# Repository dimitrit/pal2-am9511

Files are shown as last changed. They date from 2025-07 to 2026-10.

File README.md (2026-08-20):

AM9511 Module for the PAL-2
===========================

The AMD AM9511 Arithmetic Processing Unit, first produced in the late 
1970s, provides hardware support for high performance fixed and floating 
point arithmetic and a variety of floating point trigonometric and 
mathematical operations, for use with microprocessors of that period.

This repository provides schematics and board design for a module that
can be connected to the PAL-2 Expansion interface.

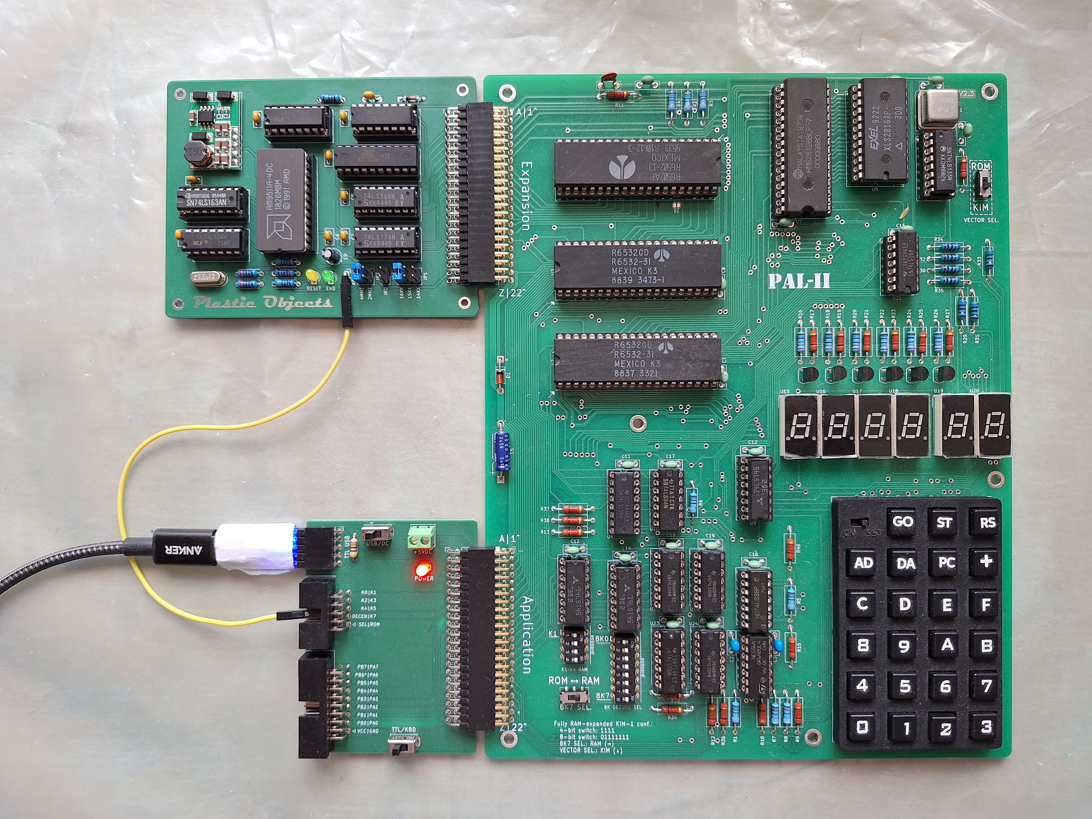
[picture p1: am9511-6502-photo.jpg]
module photo


The design is adapted from the work of Harris[1], who in turn based 
his implementation on designs by Kissel and Currie[2] in which they 
developed an experiment using a MOS 6502 microprocessor to control 
four AM9511A floating-point arithmetic units, and from Hart’s 
MICROCRUNCH[3] which also used the AM9511A (Intel 8231A) interfaced 
with a (Rockwell) 6502.

See [am9511-6502-description.pdf](am9511-6502-description.pdf) for a
full description of the interface circuit design and 
[am9511-6502-schematic.pdf](am9511-6502-schematic.pdf) for the schematic.

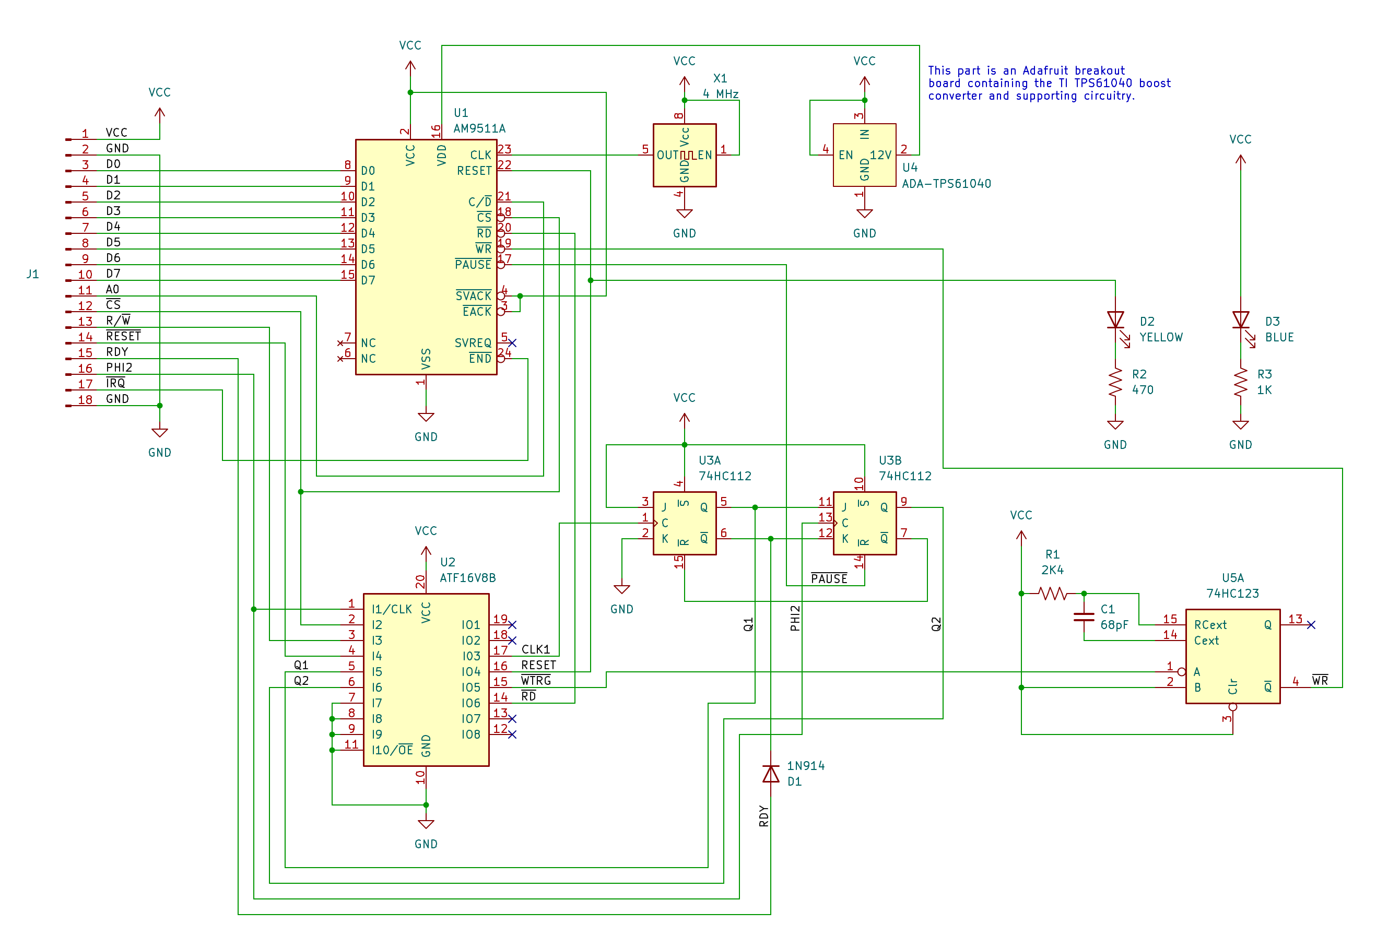
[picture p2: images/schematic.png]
Schematic


The specification here anticipates the use of an AM9511A clocked at
4 MHz. However, the same design will work with earlier versions of the 
AM9511, by setting JP to 2Mhz or by swapping the 4 MHz clock oscillator 
with a unit of an appropriately lower speed.

The `logic` folder contains the programming details for the ATF16V8B
used in the circuit, as produced by [Galette](https://github.com/simon-frankau/galette) 
from the `am9511-logic.pld` source file. The provided JEDEC file
(`am9511-logic.jed`) can be easily programmed into an ATF16V8B using 
[minipro](https://gitlab.com/DavidGriffith/minipro).

Also included in the `docs` folder are source documents cited below, as 
well as datasheets and supplementary documents for the AM9511.

---
1. Harris, CE: "AM9511 Interface Module for the 6502"; July 2025; [GitHub](https://github.com/ceharris/am9511-6502)
2. Kissel, R and Currie, J: "Hardware Math for the 6502 Microprocessor"; 
   July 1985; NASA TM-86517
3. Hart, J: "MICROCRUNCH: An Ultra-Fast Arithmetic Computing System 
   (part 1)"; August 1981; MICRO - the 6502/6809 Journal (No. 39)

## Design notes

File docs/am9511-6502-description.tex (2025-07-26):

\documentclass[11pt, letterpaper]{article}
\usepackage[letterpaper, margin=1in]{geometry}
\usepackage{graphicx}
\usepackage[dvipsnames]{xcolor}
\definecolor{linkbordergray}{rgb}{0.8,0.8,0.8}
\usepackage[linkbordercolor=linkbordergray]{hyperref}
\graphicspath{{images/}}

\newcommand{\overbar}[1]{\mkern 1.5mu\overline{\mkern-1.5mu#1\mkern-1.5mu}\mkern 1.5mu}

\title{AM9511 Interface for the 6502}
\author{Carl Harris}
\date{December 2024}
\begin{document}
\maketitle
\noindent 
The AMD AM9511 Arithmetic Processing Unit, first produced in the late 1970s, 
provides high performance fixed or floating point arithmetic as well as
common transcendental functions. It provides an excellent enhancement to any 
retro-computer that will be used to perform fixed-point or floating-point 
mathematical operations. At present, these parts are obtainable from various 
suppliers as new-old stock or used stock.

This article describes an interface allowing the AM9511A to be directly 
connected to the bus of the 6502 microprocessor. It is adapted from the work 
of Kissel and Currie\footnote{Kissel, R and Currie, J: 
\emph{Hardware Math for the 6502 Microprocessor}; July 1985; 
NASA TM-86517} in which they developed an experiment using a MOS 6502 
microprocessor to control four AM9511A floating-point arithmetic units. It
also includes elements of Hart’s MICROCRUNCH\footnote{Hart, J: 
\emph{MICROCRUNCH: An Ultra-Fast Arithmetic Computing System (part 1)}; 
August 1981; MICRO - the 6502/6809 Journal} which used the AM9511A 
(Intel 8231A) interfaced with a (Rockwell) 6502.

\section{Bus Interface Design}
The AM9511 uses an asynchronous interface design --- its timing is not derived 
from the clock of the host microprocessor. This allows the AM9511A to be 
clocked at 4 MHz while, in the case of the original 6502, the system clock 
is only 1 MHz. A disadvantage of this approach is that the interface has 
some strict timing requirements to ensure that the actions of the AM9511 
and the microprocessor are effectively coordinated, despite the lack of a 
shared clock.

The bus signal timing requirements of the AM9511 are generally easy to 
satisfy using microprocessors such as the 8080, 8085, or Z80, which
are designed to use multiple clock cycles for each machine cycle. In such 
systems, the bus control signals for addressing or read/write control are 
changed over the course of multiple clock cycles, with addressing (chip 
selection) happening first, followed by changes to read or write signals 
in later cycles. At the end of a cycle, the read and write signals change
first, before changes to the address lines.

In the 6502, after the falling edge of the clock, addressing and read/write 
selection are stabilized at effectively the same time. At the next rising 
clock edge, a read or write operation occurs, ending at the subsequent 
falling edge, at which time the addressing and read/write selection signals 
are subject to change again.

The AM9511 requires the address input ($C/\overbar{D}$) to be stable before 
the chip select ($\overbar{CS}$) and read ($\overbar{RD}$) or write 
($\overbar{WR}$) signals are asserted. The minimum delay between the fall of 
$\overbar{CS}$ and the fall of either $\overbar{RD}$ or $\overbar{WR}$ is 
given as zero, which simply means that $\overbar{RD}$ or $\overbar{WR}$ 
cannot precede $\overbar{CS}$. This is generally easy to satisfy in a 
6502-based system.

The first complication involves write operations. The AM9511 requires a 
minimum positive delay between the rise of the $\overbar{WR}$ signal (at 
the end of a write operation) and the rise of the $\overbar{CS}$ signal. 
Depending on the specific AM9511 part, this delay requirement could be as 
high as 60 ns. Obviously, this requirement precludes direct use of the 
$R/\overbar{W}$ signal as the input to $\overbar{WR}$, since $R/\overbar{W}$ 
changes state coincident with the address lines, soon after the falling edge 
of the $PHI2$ clock.

As suggested by Hart, the solution here uses a monostable multivibrator to 
effectively control the length of the low pulse on the $\overbar{WR}$ signal. 
As shown in Figure \ref{fig:schematic}, the circuit uses a 74HC123 
monostable multivibrator. This specific part is used because it can deliver
an output pulse of a fixed duration, without regard to the length of the 
trigger pulse. The combination of a 68 pF capacitor and a 2.4 K\textohm\  resistor 
provides an output pulse of approximately 75 ns which is sufficient to meet 
the delay requirement for any AM9511 part, while still being significantly 
shorter than one half of the $PHI2$ clock period (assuming a clock speed of 2
MHz or less).

\begin{figure}[h]
\centering

\caption{Circuit Schematic}
\label{fig:schematic}
\end{figure}

In a read operation, it is assumed that the microprocessor will 
set $C/\overbar{D}$, then assert $\overbar{CS}$ and $\overbar{RD}$.
The AM9511 then asserts its $\overbar{PAUSE}$ output, which remains 
low until the requested data is available on lines $D[0..7]$. When 
the data is available, the AM9511 releases $\overbar{PAUSE}$ and lines
$D[0..7]$ remain stable until $\overbar{RD}$, $\overbar{CS}$, 
or $C/\overbar{D}$ changes. The minimum delay between the rise of 
the $\overbar{RD}$ input and the rise of the $\overbar{CS}$ input is 
given as zero --- in particular, this implies that $\overbar{RD}$ 
cannot rise \emph{after} $\overbar{CS}$.

The intent of the $\overbar{PAUSE}$ signal in a read operation is to 
force the microprocessor to wait until data requested from the AM9511 
becomes available on the bus. The 6502 has an active high $RDY$ input 
for this purpose. A complication arises from the fact that the 6502 
observes the state of this input on the rising edge of the $PHI2$ 
clock --- i.e. at the instant at which the 6502 would perform the read 
operation, if $RDY$ is low the 6502 will instead wait until the next 
rising edge of the clock at which time it will again observe 
the state of RDY. After $\overbar{RD}$ is asserted, the AM9511 may 
require as much as 150 ns before $\overbar{PAUSE}$ is asserted. 
Depending on the $PHI2$ clock frequency and the time that it takes for 
the address and $R/\overbar{W}$ lines to settle, this could occur 
\emph{after} the rising edge of the clock cycle in which the read 
operation was initiated. This implies that we must arrange to pull the
RDY signal low \emph{before} the first rising edge in a machine cycle
that will read from the AM9511, anticipating that the AM9511 will
subsequently assert $\overbar{PAUSE}$.

Asserting the AM9511's $\overbar{RD}$ after the falling edge of $PHI2$ 
is complicated by the fact that the 6502 can arbitrarily change the 
state of the address lines and $R/\overbar{W}$ immediately after the 
falling edge of the $PHI2$ clock. We must be careful to avoid asserting 
$\overbar{RD}$ spuriously while the 6502's signals are settling --- 
doing so could inadvertently trigger a read operation, unexpectedly 
disrupting the state of the AM9511's stack.

To solve both of these complications with read operations, the solution
here is basically the same as that used by Kissel and Currie -- a pair 
of JK flip-flops that latch $RDY$ in the low state at the beginning of an
operation, and reset it to the high state after the $\overbar{PAUSE}$ 
signal rises. The state of these flip-flops is also used as an enable for 
the $\overbar{RD}$ signal.

This circuit uses a programmable logic device (ATF16V8) to implement the 
necessary combinatorial logic. This could also be done with discrete 7400 
series logic circuits, but the ATF16V8 is readily available and easily 
programmed using open-source tools Galette\footnote{\emph{Galette: A 
GAL assembler, largely galasm-compatible and written in Rust}; \\
\url{https://github.com/simon-frankau/galette}} 
and Minipro\footnote{\emph{Minipro: An open source program for controlling 
the MiniPRO TL866xx series of chip programmers}; \\
\url{https://gitlab.com/DavidGriffith/minipro}}. 
Figure 
\ref{fig:pld-logic} shows the logic programmed into the PLD.

\begin{figure}[h]
\centering

\caption{Combinatorial Logic}
\label{fig:pld-logic}
\end{figure}

With this logic, the $\overbar{WTRG}$ signal is asserted at the rising
edge of $PHI2$ if the $\overbar{CS}$ signal is asserted and $R/\overbar{W}$ 
is low. This output provides the trigger input for the 74HC123 used to 
produce the $\overbar{WR}$ pulse for the AM9511.

The $Q1$ and $Q2$ inputs to this logic are the corresponding outputs of 
the JK flip-flops. These are logically OR'ed as an enable signal to prevent 
$\overbar{RD}$ from being asserted spuriously. The CLK1 output connects to 
the clock input of the first flip-flop. Since the 74HC112 has a negative 
edge trigger, the falling edge of this signal (when $\overbar{CS}$ is 
asserted and R/$\overbar{W}$ is high) clocks a logic one into the first 
flip-flop, and simultaneously drives the $\overbar{RD}$ signal low.

The $\overbar{Q1}$ output of the first flip-flop is connected to the 6502’s 
$RDY$ input, so a logic one in this flip-flop signals to the 6502 that it 
should wait at the next rising edge of $PHI2$. The clock input of the second 
flip-flop is tied to $PHI2$, so at the next falling edge of $PHI2$ for which 
the AM9511’s $\overbar{PAUSE}$ output is not asserted, the second flip-flop 
will clock in a logic one. Output $Q2$ will be high, so $\overbar{RD}$ will 
continue to be asserted even though output $\overbar{Q2}$ will reset the 
first flip-flop, signaling to the 6502 that it can continue. The next rising 
edge of the $PHI2$ will complete the read operation, and the subsequent 
falling edge of $PHI2$ will cause the second flip-flop to clock in a logic 
zero (because $J2$ is low while $K2$ is high).

The only other significant elements of the circuit are the 4 MHz clock 
oscillator and a boost converter.

The AM9511A-4DC can run at 4 MHz. Other parts, such as the AM9511A-1DC require 
a clock speed no greater than 3 MHz. I decided to use a dedicated on-board
clock oscillator mostly as a matter of convenience. Of course, the AM9511 could
be clocked by the system clock (with an appropriate divider circuit if necessary).

The AM9511 requires a +12V DC bias input. I choose to use a boost converter
since the current requirement is quite small, and doing so avoids the complication
of a having multiple DC supplies at different voltages. The boost converter depicted
in the schematic is a breakout board made by Adafruit. However, any +5 VDC to +12 VDC 
boost converter should be fine --- only about 100 mA current is needed at +12 VDC. 

\section{Other Considerations}

The interface described herein does not provide a mechanism to wait after a write
operation. This means that even though the AM9511 asserts the $\overbar{PAUSE}$ 
signal while executing a requested operation, the 6502 will not wait until the 
requested operation is completed. This allows the programmer to decide how best 
to use the time during which an operation is executing. One simple approach is 
to simply poll the BUSY flag in the AM9511's status register in a loop
to determine when a requested operation has completed execution. 

Alternatively, the hardware could make use of the $\overbar{END}$ signal (or 
$SVREQ$ signal) as an interrupt source to allow other work to be completed 
concurrently while the AM9511 is executing operations. The module described 
here can connect $\overbar{END}$ to the 6502's $\overbar{IRQ}$ input if desired.
The $\overbar{END}$ signal is an open-drain output, allowing it to be easily
incorporated into a design that uses a wired-OR configuration for multiple
devices connected to the 6502's $\overbar{IRQ}$ input.

Furht and Lee\footnote{Furht, B and Lee, P: \emph{An Efficient Software Driver 
for AM9511 Arithmetic Processor Implementation}; June 1984; IEEE Micro, Volume 4
Issue 3} describe an interrupt-driven approach for the 8085 microprocessor that
could be adapted for the 6502. Using such a design, is it possible to enqueue a
sequence of interdependent operations in main memory, pushing operands and
operations onto the AM9511's stack as soon as it is able to accommodate them.

\pagebreak
\section{Observed Timing}

The following oscilloscope plots show key aspects of the interface timing as 
observed using a WDC 65C02 clocked at 1.8432 MHz and the AM9511A clocked at 
4 MHz.

\subsection{Write Operation}

Figure \ref{fig:write-timing} shows the timing for a write operation. A 
write operation targeting the dataregister versus the command register differs 
only in the value of the $C/\overbar{D}$ signal (shown here as $A0$) --- it is 
high here signifying a write to the command register. Note that the 
$\overbar{WR}$ pulse falls soon after the rising edge of $PHI2$ but rises 
approximately 75 ns before either $\overbar{CS}$ or $A0$ changes state. This 
satisfies what amounts to the most critical timing constraint of the AM9511.

\begin{figure}[h]
\centering

\caption{Write Operation Timing}
\label{fig:write-timing}
\end{figure}

\pagebreak
\subsection{Read Operation}

Figure \ref{fig:read-timing} shows the timing of a read operation. The 
$C/\overbar{D}$ input is not shown here since the scope has but four analog 
channels. However, this signal follows the same timing as the $\overbar{CS}$ 
signal. Here we can see that when $\overbar{CS}$ is asserted, the 
$\overbar{RD}$ signal goes low after a short delay.  In response to the read 
request, the AM9511 pulls $\overbar{PAUSE}$ low indicating that it is busy 
accessing the requested data. After the $\overbar{PAUSE}$ signal rises, at 
the next rising edge of $PHI2$, the read operation is completed. By counting 
the rising edges between the transitions of $\overbar{CS}$ from high to low 
and back to high again, we can see that a total of four cycles were needed to 
complete the read operation.

\begin{figure}[h]
\centering

\caption{Read Operation Timing}
\label{fig:read-timing}
\end{figure}

\pagebreak
\subsection{Timing of the RDY Signal}

In order to see the timing associated with the 6502’s $RDY$ signal, in Figure 
\ref{fig:read-ready}, $\overbar{RD}$ has been replaced with $RDY$. As shown
in Figure \ref{fig:read-timing}, $\overbar{RD}$ has essentially the same timing 
as $\overbar{CS}$ so they can be considered equivalent for our purposes here.

Note that $RDY$ falls at virtually the same instant as $\overbar{CS}$ as the 
first flip-flop is clocked to logic one by $\overbar{CS}$ whenever the 6502’s 
$R/\overbar{W}$ signal is high. Subsequently, the $\overbar{PAUSE}$ signal 
goes low, preventing the second flip-flop from clocking in logic one on 
subsequent falling edges of PHI2. Before the third falling edge of $PHI2$, 
$\overbar{PAUSE}$ rises, and subsequently the second flip-flop clocks in a 
logic one, causing the first flip-flop to reset and asserting $RDY$. This 
allows the read operation to be completed at the next rising edge of $PHI2$.

\begin{figure}[h]
\centering

\caption{RDY Signal Timing}
\label{fig:read-ready}
\end{figure}

\end{document}

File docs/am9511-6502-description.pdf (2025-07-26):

## AM9511 Interface for the 6502

Carl Harris

December 2024

The AMD AM9511 Arithmetic Processing Unit, first produced in the late 1970s, provides high performance fixed or floating point arithmetic as well as common transcendental functions. It provides an excellent enhancement to any retro-computer that will be used to perform fixed-point or floating-point mathematical operations. At present, these parts are obtainable from various suppliers as new-old stock or used stock.
This article describes an interface allowing the AM9511A to be directly connected to the bus of the 6502 microprocessor. It is adapted from the work of Kissel and Currie¹
in which they developed
an experiment using a MOS 6502 microprocessor to control four AM9511A floating-point arithmetic units. It also includes elements of Hart’s MICROCRUNCH² which used the AM9511A (Intel 8231A) interfaced with a (Rockwell) 6502.

## 1 Bus Interface Design

The AM9511 uses an asynchronous interface design — its timing is not derived from the clock of the host microprocessor. This allows the AM9511A to be clocked at 4 MHz while, in the case of the original 6502, the system clock is only 1 MHz. A disadvantage of this approach is that the interface has some strict timing requirements to ensure that the actions of the AM9511 and the microprocessor are effectively coordinated, despite the lack of a shared clock.
The bus signal timing requirements of the AM9511 are generally easy to satisfy using micro-processors such as the 8080, 8085, or Z80, which are designed to use multiple clock cycles for each machine cycle. In such systems, the bus control signals for addressing or read/write control are changed over the course of multiple clock cycles, with addressing (chip selection) happening first, followed by changes to read or write signals in later cycles. At the end of a cycle, the read and write signals change first, before changes to the address lines.
In the 6502, after the falling edge of the clock, addressing and read/write selection are stabilized at effectively the same time. At the next rising clock edge, a read or write operation occurs, ending at the subsequent falling edge, at which time the addressing and read/write selection signals are subject to change again.
The AM9511 requires the address input (C/D) to be stable before the chip select (CS) and read (RD) or write (W R) signals are asserted. The minimum delay between the fall of CS and the fall of either RD or W R is given as zero, which simply means that RD or W R cannot precede CS. This is generally easy to satisfy in a 6502-based system.
The first complication involves write operations. The AM9511 requires a minimum positive delay between the rise of the W R signal (at the end of a write operation) and the rise of the CS

1Kissel, R and Currie, J: Hardware Math for the 6502 Microprocessor; July 1985; NASA TM-86517
2Hart, J: MICROCRUNCH: An Ultra-Fast Arithmetic Computing System (part 1); August 1981; MICRO - the 6502/6809 Journal signal. Depending on the specific AM9511 part, this delay requirement could be as high as 60 ns. Obviously, this requirement precludes direct use of the R/W signal as the input to W R, since R/W changes state coincident with the address lines, soon after the falling edge of the P HI2 clock.
As suggested by Hart, the solution here uses a monostable multivibrator to effectively control the length of the low pulse on the W R signal. As shown in Figure 1, the circuit uses a 74HC123 monostable multivibrator. This specific part is used because it can deliver an output pulse of a fixed duration, without regard to the length of the trigger pulse. The combination of a 68 pF capacitor and a 2.4 KΩ resistor provides an output pulse of approximately 75 ns which is sufficient to meet the delay requirement for any AM9511 part, while still being significantly shorter than one half of the P HI2 clock period (assuming a clock speed of 2 MHz or less).


Figure 1: Circuit Schematic

In a read operation, it is assumed that the microprocessor will set C/D, then assert CS and RD. The AM9511 then asserts its P AUSE output, which remains low until the requested data is available on lines D[0..7]. When the data is available, the AM9511 releases P AUSE and lines D[0..7] remain stable until RD, CS, or C/D changes. The minimum delay between the rise of the RD input and the rise of the CS input is given as zero — in particular, this implies that RD cannot rise after CS.
The intent of the P AUSE signal in a read operation is to force the microprocessor to wait until data requested from the AM9511 becomes available on the bus. The 6502 has an active high RDY input for this purpose. A complication arises from the fact that the 6502 observes the state of this input on the rising edge of the P HI2 clock — i.e. at the instant at which the 6502 would perform the read operation, if RDY is low the 6502 will instead wait until the next rising edge of the clock at which time it will again observe the state of RDY. After RD is asserted, the AM9511 may require as much as 150 ns before P AUSE is asserted. Depending on the PHI2 clock frequency and the time that it takes for the address and R/W lines to settle, this could occur after the rising edge of the clock cycle in which the read operation was initiated. This implies that we must arrange to pull the RDY signal low before the first rising edge in a machine cycle that will read from the AM9511, anticipating that the AM9511 will subsequently assert P AUSE.
Asserting the AM9511’s RD after the falling edge of P HI2 is complicated by the fact that the 6502 can arbitrarily change the state of the address lines and R/W immediately after the falling edge of the P HI2 clock. We must be careful to avoid asserting RD spuriously while the 6502’s signals are settling — doing so could inadvertently trigger a read operation, unexpectedly disrupting the state of the AM9511’s stack.
To solve both of these complications with read operations, the solution here is basically the same as that used by Kissel and Currie – a pair of JK flip-flops that latch RDY in the low state at the beginning of an operation, and reset it to the high state after the P AUSE signal rises. The state of these flip-flops is also used as an enable for the RD signal.
This circuit uses a programmable logic device (ATF16V8) to implement the necessary combinatorial logic. This could also be done with discrete 7400 series logic circuits, but the ATF16V8 is readily available and easily programmed using open-source tools Galette³ and Minipro⁴
. Figure 2
shows the logic programmed into the PLD.

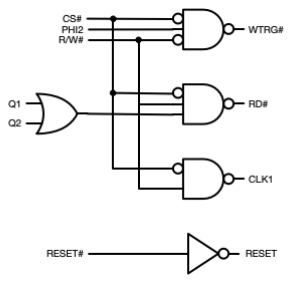
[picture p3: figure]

Figure 2: Combinatorial Logic

With this logic, the W T RG signal is asserted at the rising edge of P HI2 if the CS signal is

3Galette: A GAL assembler, largely galasm-compatible and written in Rust; https://github.com/simon-frankau/galette
4Minipro: An open source program for controlling the MiniPRO TL866xx series of chip programmers; https://gitlab.com/DavidGriffith/minipro asserted and R/W is low. This output provides the trigger input for the 74HC123 used to produce the W R pulse for the AM9511.
The Q1 and Q2 inputs to this logic are the corresponding outputs of the JK flip-flops. These are logically OR’ed as an enable signal to prevent RD from being asserted spuriously. The CLK1 output connects to the clock input of the first flip-flop. Since the 74HC112 has a negative edge trigger, the falling edge of this signal (when CS is asserted and R/W is high) clocks a logic one into the first flip-flop, and simultaneously drives the RD signal low.
The Q1 output of the first flip-flop is connected to the 6502’s RDY input, so a logic one in this flip-flop signals to the 6502 that it should wait at the next rising edge of P HI2. The clock input of the second flip-flop is tied to P HI2, so at the next falling edge of P HI2 for which the AM9511’s P AUSE output is not asserted, the second flip-flop will clock in a logic one. Output Q2 will be high, so RD will continue to be asserted even though output Q2 will reset the first flip-flop, signaling to the 6502 that it can continue. The next rising edge of the P HI2 will complete the read operation, and the subsequent falling edge of P HI2 will cause the second flip-flop to clock in a logic zero (because J2 is low while K2 is high).
The only other significant elements of the circuit are the 4 MHz clock oscillator and a boost converter.
The AM9511A-4DC can run at 4 MHz. Other parts, such as the AM9511A-1DC require a clock speed no greater than 3 MHz. I decided to use a dedicated on-board clock oscillator mostly as a matter of convenience. Of course, the AM9511 could be clocked by the system clock (with an appropriate divider circuit if necessary).
The AM9511 requires a +12V DC bias input. I choose to use a boost converter since the current requirement is quite small, and doing so avoids the complication of a having multiple DC supplies at different voltages. The boost converter depicted in the schematic is a breakout board made by Adafruit. However, any +5 VDC to +12 VDC boost converter should be fine — only about 100 mA current is needed at +12 VDC.

## 2 Other Considerations

The interface described herein does not provide a mechanism to wait after a write operation. This means that even though the AM9511 asserts the P AUSE signal while executing a requested operation, the 6502 will not wait until the requested operation is completed. This allows the programmer to decide how best to use the time during which an operation is executing. One simple approach is to simply poll the BUSY flag in the AM9511’s status register in a loop to determine when a requested operation has completed execution.
Alternatively, the hardware could make use of the END signal (or SV REQ signal) as an interrupt source to allow other work to be completed concurrently while the AM9511 is executing operations. The module described here can connect END to the 6502’s IRQ input if desired. The END signal is an open-drain output, allowing it to be easily incorporated into a design that uses a wired-OR configuration for multiple devices connected to the 6502’s IRQ input.
Furht and Lee⁵ describe an interrupt-driven approach for the 8085 microprocessor that could be adapted for the 6502. Using such a design, is it possible to enqueue a sequence of interdependent operations in main memory, pushing operands and operations onto the AM9511’s stack as soon as it is able to accommodate them.

5Furht, B and Lee, P: An Efficient Software Driver for AM9511 Arithmetic Processor Implementation; June 1984; IEEE Micro, Volume 4 Issue 3

## 3 Observed Timing

The following oscilloscope plots show key aspects of the interface timing as observed using a WDC 65C02 clocked at 1.8432 MHz and the AM9511A clocked at 4 MHz.

### 3.1 Write Operation

Figure 3 shows the timing for a write operation. A write operation targeting the dataregister versus the command register differs only in the value of the C/D signal (shown here as A0) — it is high here signifying a write to the command register. Note that the W R pulse falls soon after the rising edge of P HI2 but rises approximately 75 ns before either CS or A0 changes state. This satisfies what amounts to the most critical timing constraint of the AM9511.

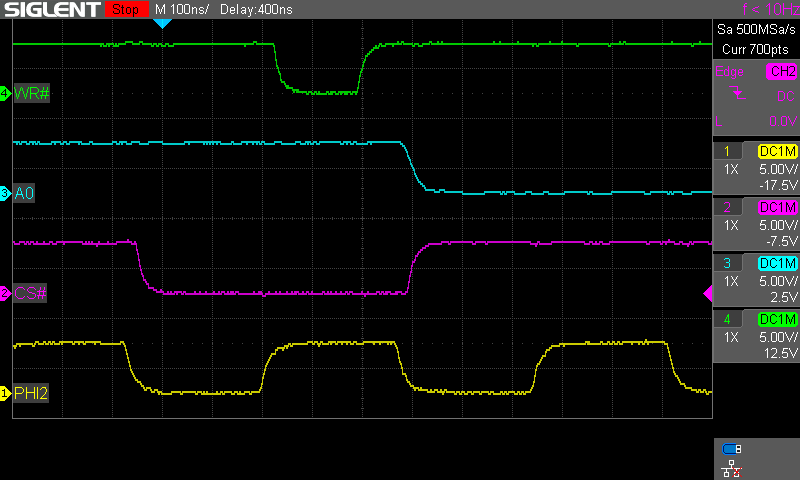
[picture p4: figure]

Figure 3: Write Operation Timing

### 3.2 Read Operation

Figure 4 shows the timing of a read operation. The C/D input is not shown here since the scope has but four analog channels. However, this signal follows the same timing as the CS signal. Here we can see that when CS is asserted, the RD signal goes low after a short delay. In response to the read request, the AM9511 pulls P AUSE low indicating that it is busy accessing the requested data. After the P AUSE signal rises, at the next rising edge of P HI2, the read operation is completed. By counting the rising edges between the transitions of CS from high to low and back to high again, we can see that a total of four cycles were needed to complete the read operation.

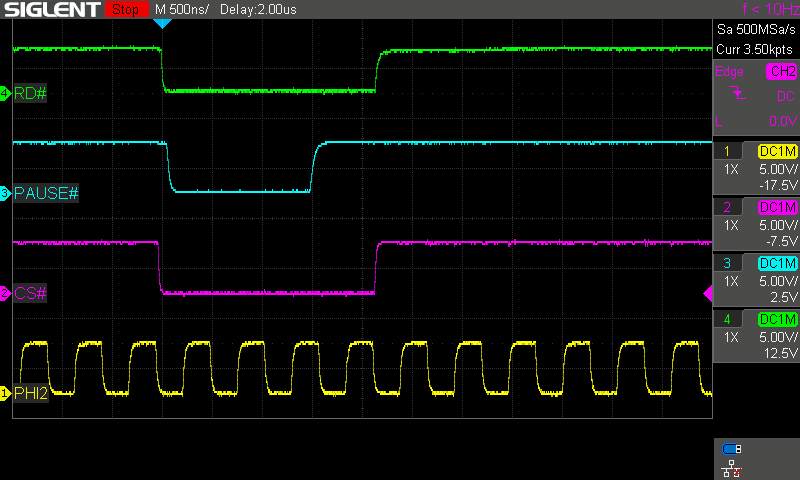
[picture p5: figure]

Figure 4: Read Operation Timing

### 3.3 Timing of the RDY Signal

In order to see the timing associated with the 6502’s RDY signal, in Figure 5, RD has been replaced with RDY . As shown in Figure 4, RD has essentially the same timing as CS so they can be considered equivalent for our purposes here.
Note that RDY falls at virtually the same instant as CS as the first flip-flop is clocked to logic one by CS whenever the 6502’s R/W signal is high. Subsequently, the P AUSE signal goes low, preventing the second flip-flop from clocking in logic one on subsequent falling edges of PHI2. Before the third falling edge of P HI2, P AUSE rises, and subsequently the second flip-flop clocks in a logic one, causing the first flip-flop to reset and asserting RDY . This allows the read operation to be completed at the next rising edge of P HI2.

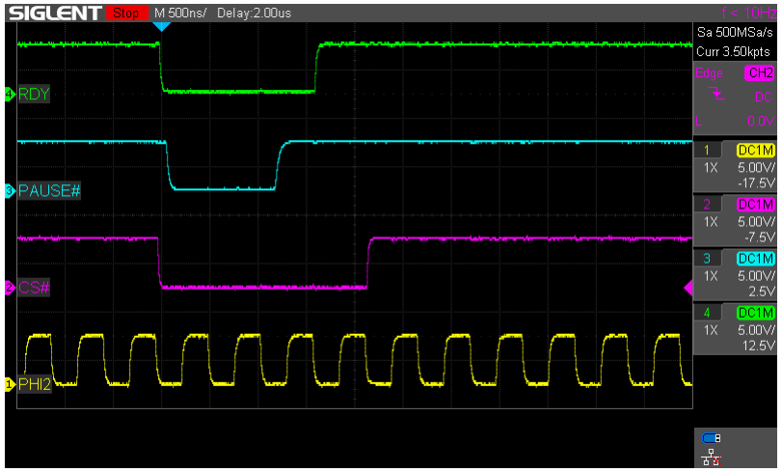
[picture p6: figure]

Figure 5: RDY Signal Timing

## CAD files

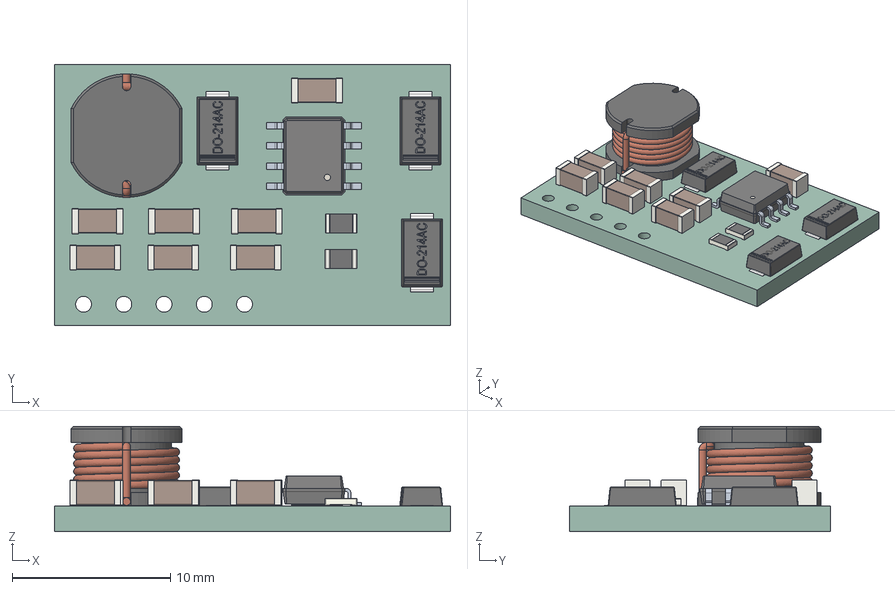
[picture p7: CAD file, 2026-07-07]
dd1718pa.step
25.0 x 16.5 x 6.63 mm
CQ assembly
C_1206_3216Metric x 7
R_0805_2012Metric x 2
DO-214AC x 3
Foundation_Solid
Top_Chamfer_Solid
Wire1
Wire2
Wire3
Wire4
Wire5
Wire6
Wire7
Wire8
Wire9
Wire10
Pinouts_Solid
dd1718pa_PCB

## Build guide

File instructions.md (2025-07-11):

Just some notes to remind me of the various steps needed to update a release
on GitHub.

1.  In KiCad, run the ERC on the schematic and the the DRC on the PCB and
    resolve any errors or warnings before proceeding.
2.  Plot the schematic as a PDF file.
3.  Delete the existing `am9511-6502-schematic.pdf` and rename `am9511-6502.pdf`
    as `am9511-6502-schematic.pdf`.
4.  Use `Export > Drawing to Clipboard` to get the schematic onto the clipboard,
    then in Preview, use Command-N to get a new image document containing the 
    drawing. Crop the schematic image to remove the drawing sheet elements. Save
    the result as `images/schematic.png`
5.  Rebuild `am9511-6502-description.pdf` from `am9511-6502-description.tex`.
6.  Generate gerbers and drill files in the `gerbers` directory. Compress
    the `gerbers` directory, delete the existing `am9511-6502-gerbers.zip` and
    rename `gerbers.zip` as `am9511-6502-gerbers.zip`.
7.  Open the PCB in the 3D viewer, turn off THT component rendering so just the
    board itself is visible, then export the front and back images as 
    `images/pcb-front.png` and `images/pcb-back.png` respectively.
8.  Remove the viewer background from the PCB images and scrub silkscreen text.
9.  Rebuild the output files in `logic` using Galette.
10. Commit and push everything to the repo on GitHub.

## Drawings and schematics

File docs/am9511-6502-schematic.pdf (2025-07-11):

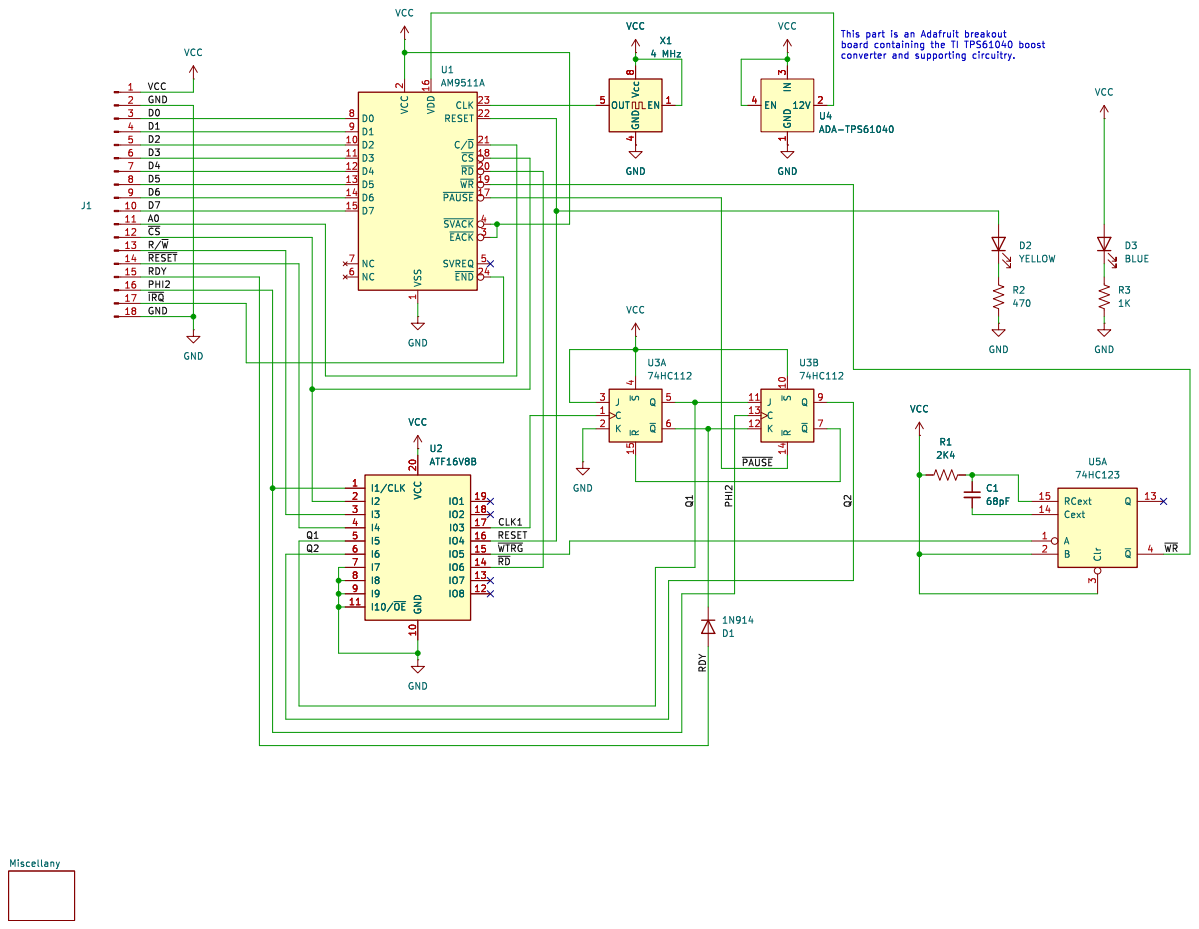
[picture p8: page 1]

1 VDD 16 CLK 23 RESET 22 C/~{D}21 ~{CS} 18 ~{RD} 20 ~{WR} 19 ~{PAUSE} 17 ~{SVACK}4 ~{EACK}3 SVREQ 5 ~{END} 24 U1AM9511A

4 OUT 5 U4 ADA-TPS61040 EN 4 IN

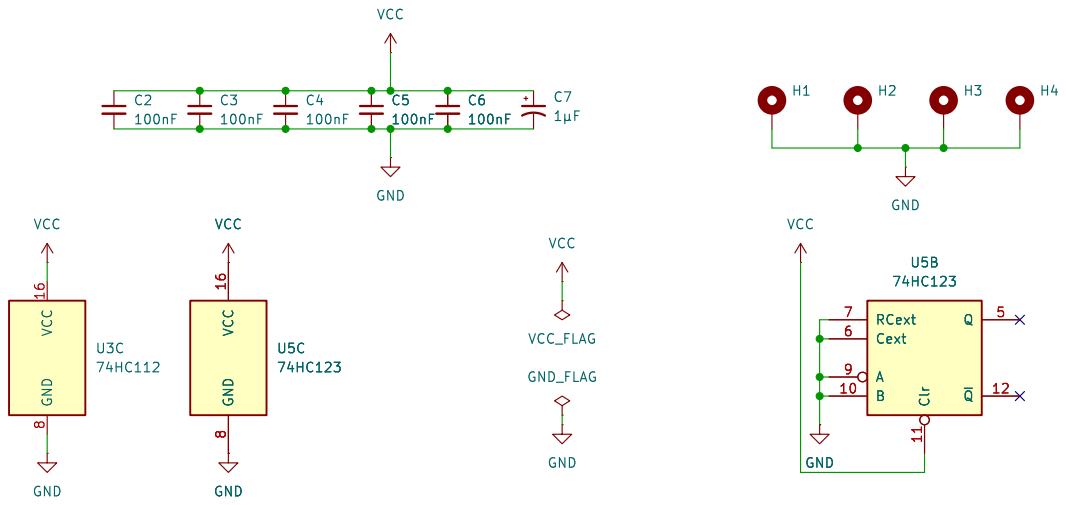
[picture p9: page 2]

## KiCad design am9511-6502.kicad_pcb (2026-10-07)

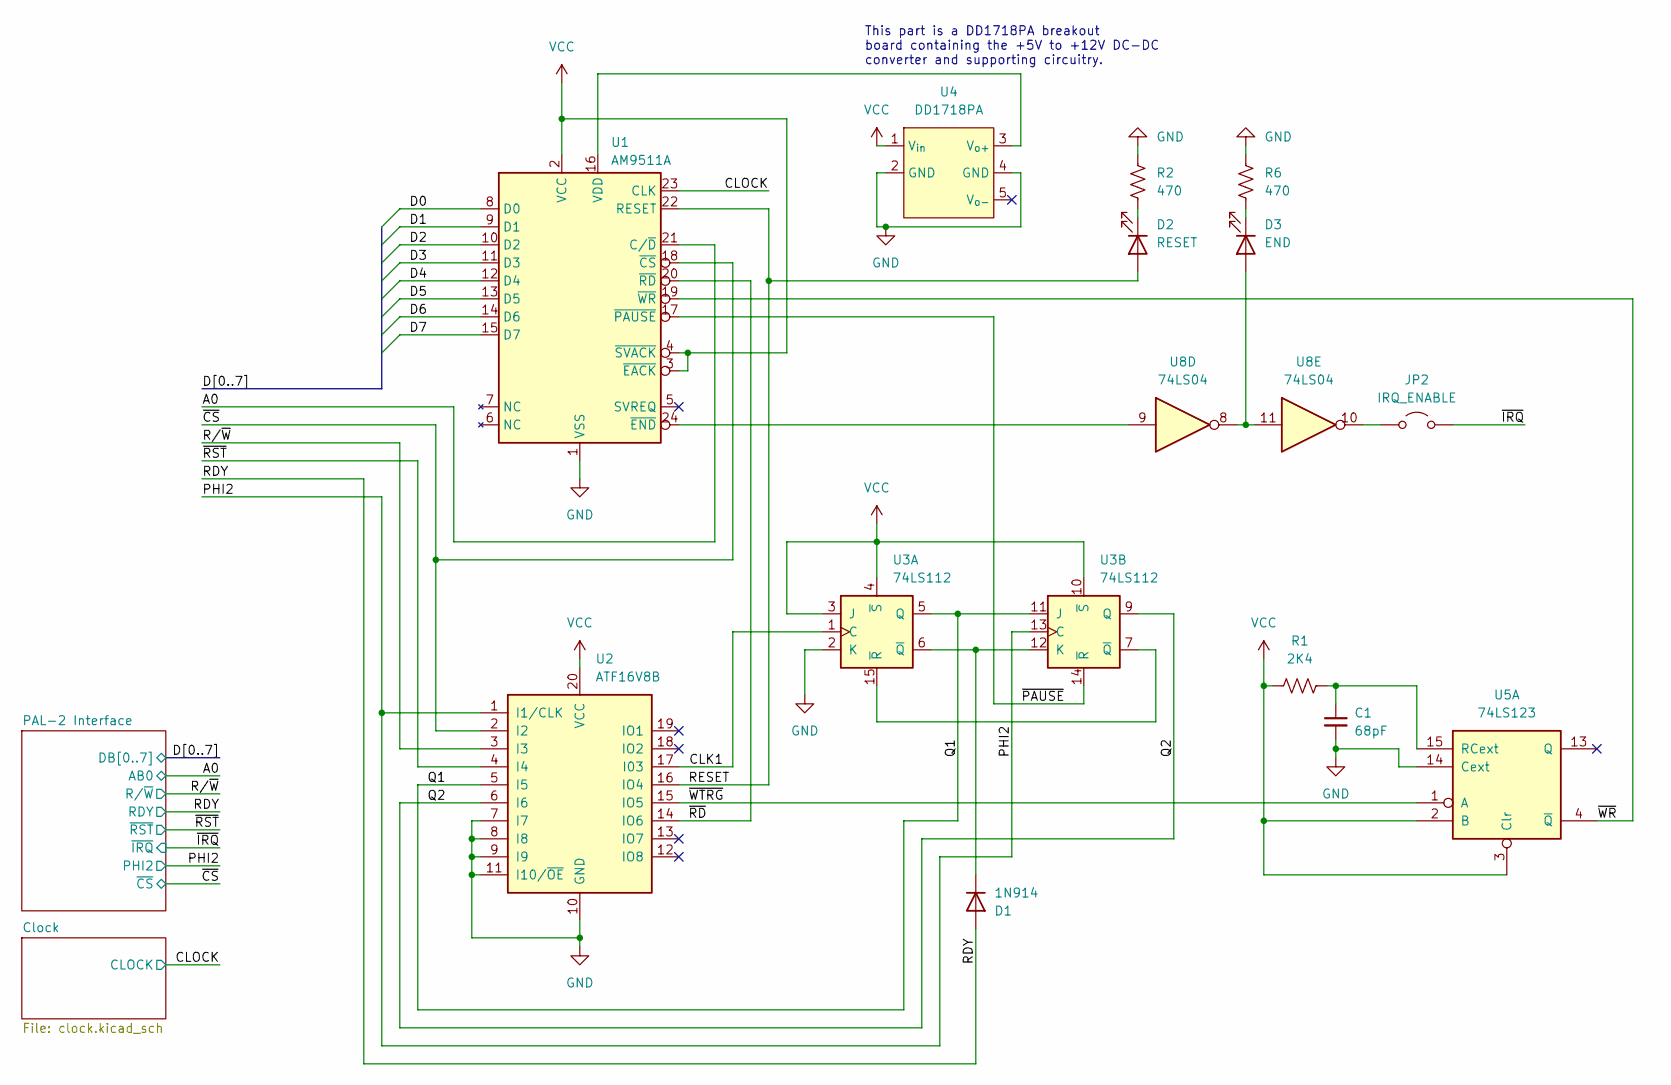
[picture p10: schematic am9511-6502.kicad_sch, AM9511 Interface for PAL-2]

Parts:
C1: 68pF; C_Disc_D5.0mm_W2.5mm_P5.00mm
D1: 1N914; D_DO-35_SOD27_P7.62mm_Horizontal
D2: RESET; LED_D3.0mm
D3: END; LED_D3.0mm
JP2: IRQ_ENABLE; PinHeader_1x02_P2.54mm_Vertical
R1: 2K4; R_Axial_DIN0207_L6.3mm_D2.5mm_P7.62mm_Horizontal
R2, R6: 470; R_Axial_DIN0207_L6.3mm_D2.5mm_P7.62mm_Horizontal
U1: AM9511A; DIP-24_W15.24mm_Socket
U2: ATF16V8B; DIP-20_W7.62mm_Socket
U3: 74LS112; DIP-16_W7.62mm_Socket
U4: DD1718PA
U5: 74LS123; DIP-16_W7.62mm_Socket
U8: 74LS04; DIP-14_W7.62mm_Socket

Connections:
/A0: U1.21 (C/~D); also elsewhere on the board
/CLK1: U2.17 (I03), U3.1 (C)
/CLOCK: U1.23 (CLK); also elsewhere on the board
/D0: U1.8 (D0); also elsewhere on the board
/D1: U1.9 (D1); also elsewhere on the board
/D2: U1.10 (D2); also elsewhere on the board
/D3: U1.11 (D3); also elsewhere on the board
/D4: U1.12 (D4); also elsewhere on the board
/D5: U1.13 (D5); also elsewhere on the board
/D6: U1.14 (D6); also elsewhere on the board
/D7: U1.15 (D7); also elsewhere on the board
/PHI2: U2.1 (I1/CLK), U3.13 (C); also elsewhere on the board
/Q1: U2.5 (I5), U3.5 (Q), U3.11 (J)
/Q2: U2.6 (I6), U3.9 (Q)
/RDY: D1.2 (A); also elsewhere on the board
/RESET: D2.2 (A), U1.22 (RESET), U2.16 (IO4)
/R/~W: U2.3 (I3); also elsewhere on the board
/~CS: U1.18 (~CS), U2.2 (I2); also elsewhere on the board
/~IRQ: JP2.1 (A); also elsewhere on the board
/~PAUSE: U1.17 (~PAUSE), U3.14 (~R)
/~RD: U1.20 (~RD), U2.14 (IO6)
/~RST: U2.4 (I4); also elsewhere on the board
/~WR: U1.19 (~WR), U5.4 (~Q)
/~WTRG: U2.15 (IO5), U5.1 (A)
GND: C1.2, R2.1, R6.1, U1.1 (VSS), U2.7 (I7), U2.8 (I8), U2.9 (I9), U2.10 (GND), U2.11 (I10/~OE), U3.2 (K), U4.2 (GND), U4.4 (GND), U5.14 (Cext); also elsewhere on the board
unnamed: D1.1 (K), U3.6 (~Q), U3.12 (K)
unnamed: D2.1 (K), R2.2
unnamed: D3.2 (A), U8.8, U8.11
unnamed: D3.1 (K), R6.2
unnamed: JP2.2 (B), U8.10
unnamed: U1.16 (VDD), U4.3 (V_{o+})
unnamed: U1.24 (~END), U8.9
unnamed: U3.7 (~Q), U3.15 (~R)
unnamed: C1.1, R1.2, U5.15 (RCext)
VCC: R1.1, U1.2 (VCC), U1.3 (~EACK), U1.4 (~SVACK), U2.20 (VCC), U3.3 (J), U3.4 (~S), U3.10 (~S), U4.1 (V_{in}), U5.2 (B), U5.3 (Clr); also elsewhere on the board

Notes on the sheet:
This part is a DD1718PA breakout board containing the +5V to +12V DC-DC converter and supporting circuitry.

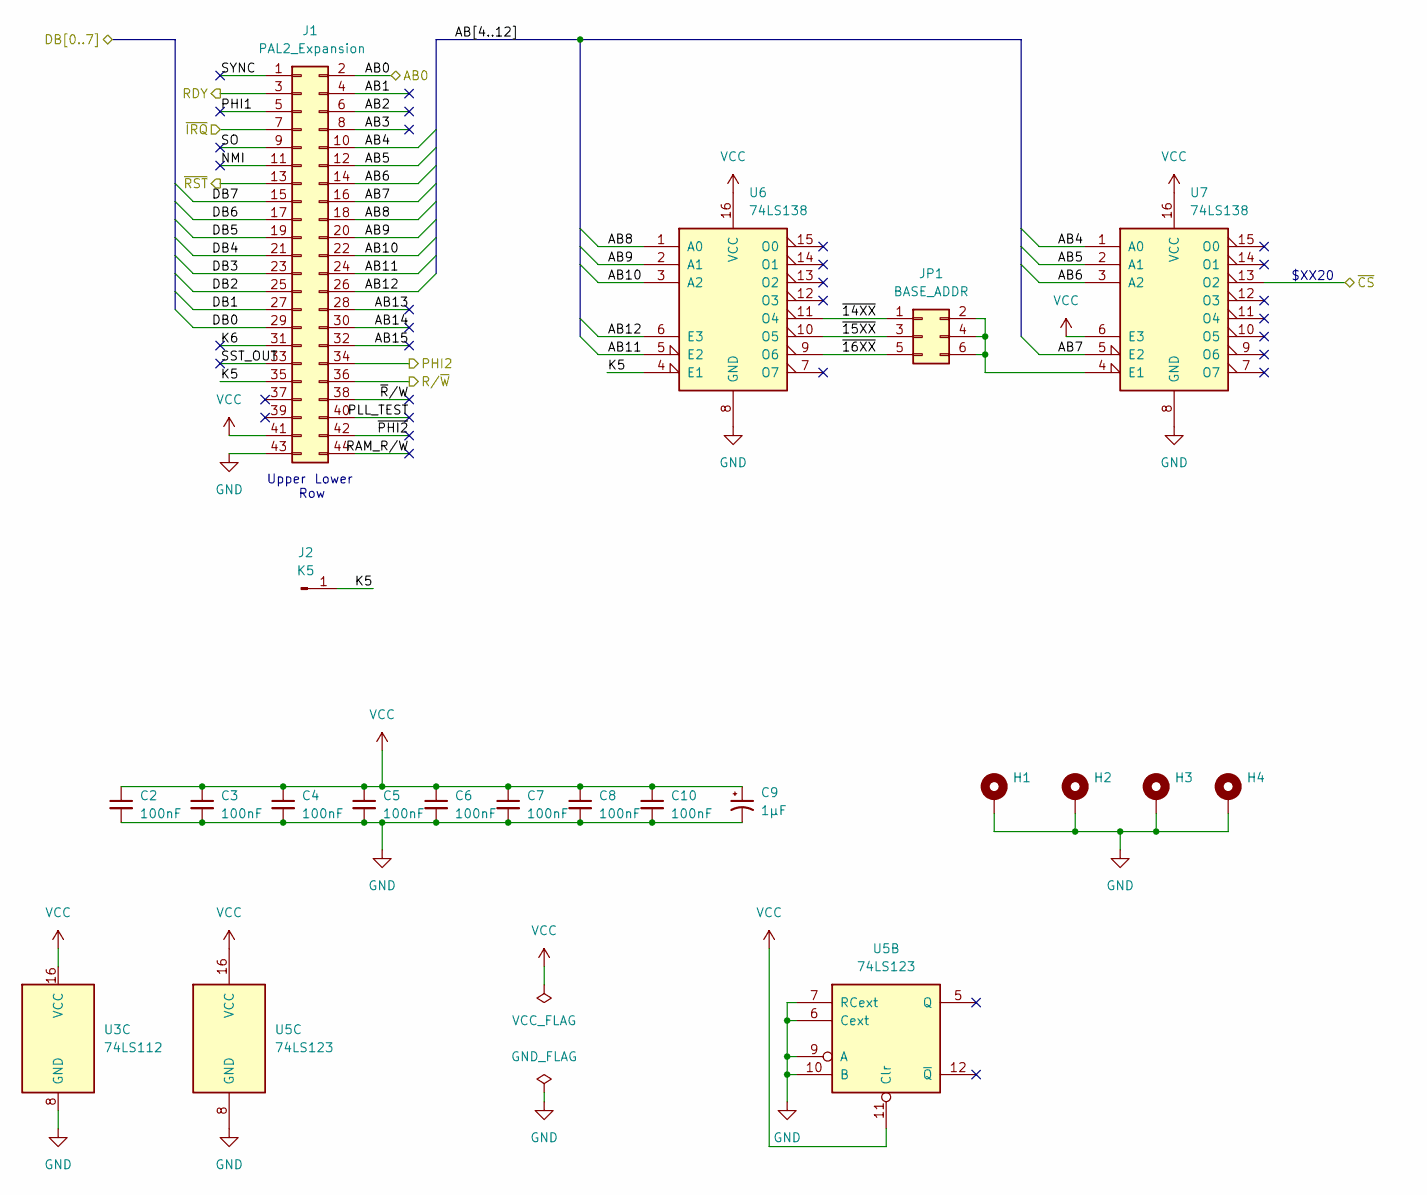
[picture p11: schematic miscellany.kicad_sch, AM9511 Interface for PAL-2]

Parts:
C2, C3, C4, C5, C6, C7, C8, C10: 100nF; C_Disc_D5.0mm_W2.5mm_P2.50mm
C9: 1µF; CP_Radial_D5.0mm_P2.50mm
H1, H2, H3, H4: MountingHole_Pad; MountingHole_2.2mm_M2_DIN965_Pad
J1: PAL2_Expansion; PinHeader_2x22_P2.54mm_Horizontal
J2: K5; PinHeader_1x01_P2.54mm_Horizontal
JP1: BASE_ADDR; PinHeader_2x03_P2.54mm_Vertical
U3: 74LS112; DIP-16_W7.62mm_Socket
U5: 74LS123; DIP-16_W7.62mm_Socket
U6, U7: 74LS138; DIP-16_W7.62mm_Socket

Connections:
/A0: J1.2; also elsewhere on the board
/D0: J1.29; also elsewhere on the board
/D1: J1.27; also elsewhere on the board
/D2: J1.25; also elsewhere on the board
/D3: J1.23; also elsewhere on the board
/D4: J1.21; also elsewhere on the board
/D5: J1.19; also elsewhere on the board
/D6: J1.17; also elsewhere on the board
/D7: J1.15; also elsewhere on the board
/PAL-2 Interface/AB1: J1.4
/PAL-2 Interface/AB2: J1.6
/PAL-2 Interface/AB3: J1.8
/PAL-2 Interface/AB4: J1.10, U7.1 (A0)
/PAL-2 Interface/AB5: J1.12, U7.2 (A1)
/PAL-2 Interface/AB6: J1.14, U7.3 (A2)
/PAL-2 Interface/AB7: J1.16, U7.5 (E2)
/PAL-2 Interface/AB8: J1.18, U6.1 (A0)
/PAL-2 Interface/AB9: J1.20, U6.2 (A1)
/PAL-2 Interface/AB10: J1.22, U6.3 (A2)
/PAL-2 Interface/AB11: J1.24, U6.5 (E2)
/PAL-2 Interface/AB12: J1.26, U6.6 (E3)
/PAL-2 Interface/AB13: J1.28
/PAL-2 Interface/AB14: J1.30
/PAL-2 Interface/AB15: J1.32
/PAL-2 Interface/K5: J1.35, J2.1, U6.4 (E1)
/PAL-2 Interface/K6: J1.31
/PAL-2 Interface/NMI: J1.11
/PAL-2 Interface/PHI1: J1.5
/PAL-2 Interface/PLL_TEST: J1.40
/PAL-2 Interface/RAM_R/W: J1.44
/PAL-2 Interface/SO: J1.9
/PAL-2 Interface/SST_OUT: J1.33
/PAL-2 Interface/SYNC: J1.1
/PAL-2 Interface/~14XX: JP1.1, U6.11 (O4)
/PAL-2 Interface/~15XX: JP1.3, U6.10 (O5)
/PAL-2 Interface/~16XX: JP1.5, U6.9 (O6)
/PAL-2 Interface/~PHI2: J1.42
/PAL-2 Interface/~R/W: J1.38
/PHI2: J1.34; also elsewhere on the board
/RDY: J1.3; also elsewhere on the board
/R/~W: J1.36; also elsewhere on the board
/~CS: U7.13 (O2); also elsewhere on the board
/~IRQ: J1.7; also elsewhere on the board
/~RST: J1.13; also elsewhere on the board
GND: C2.2, C3.2, C4.2, C5.2, C6.2, C7.2, C8.2, C9.2, C10.2, H1.1, H2.1, H3.1, H4.1, J1.43, U3.8 (GND), U5.6 (Cext), U5.7 (RCext), U5.8 (GND), U5.9 (A), U5.10 (B), U6.8 (GND), U7.8 (GND); also elsewhere on the board
unnamed: JP1.2, JP1.4, JP1.6, U7.4 (E1)
VCC: C2.1, C3.1, C4.1, C5.1, C6.1, C7.1, C8.1, C9.1, C10.1, J1.41, U3.16 (VCC), U5.11 (Clr), U5.16 (VCC), U6.16 (VCC), U7.6 (E3), U7.16 (VCC); also elsewhere on the board

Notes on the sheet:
Lower
Upper
$XX20
Row

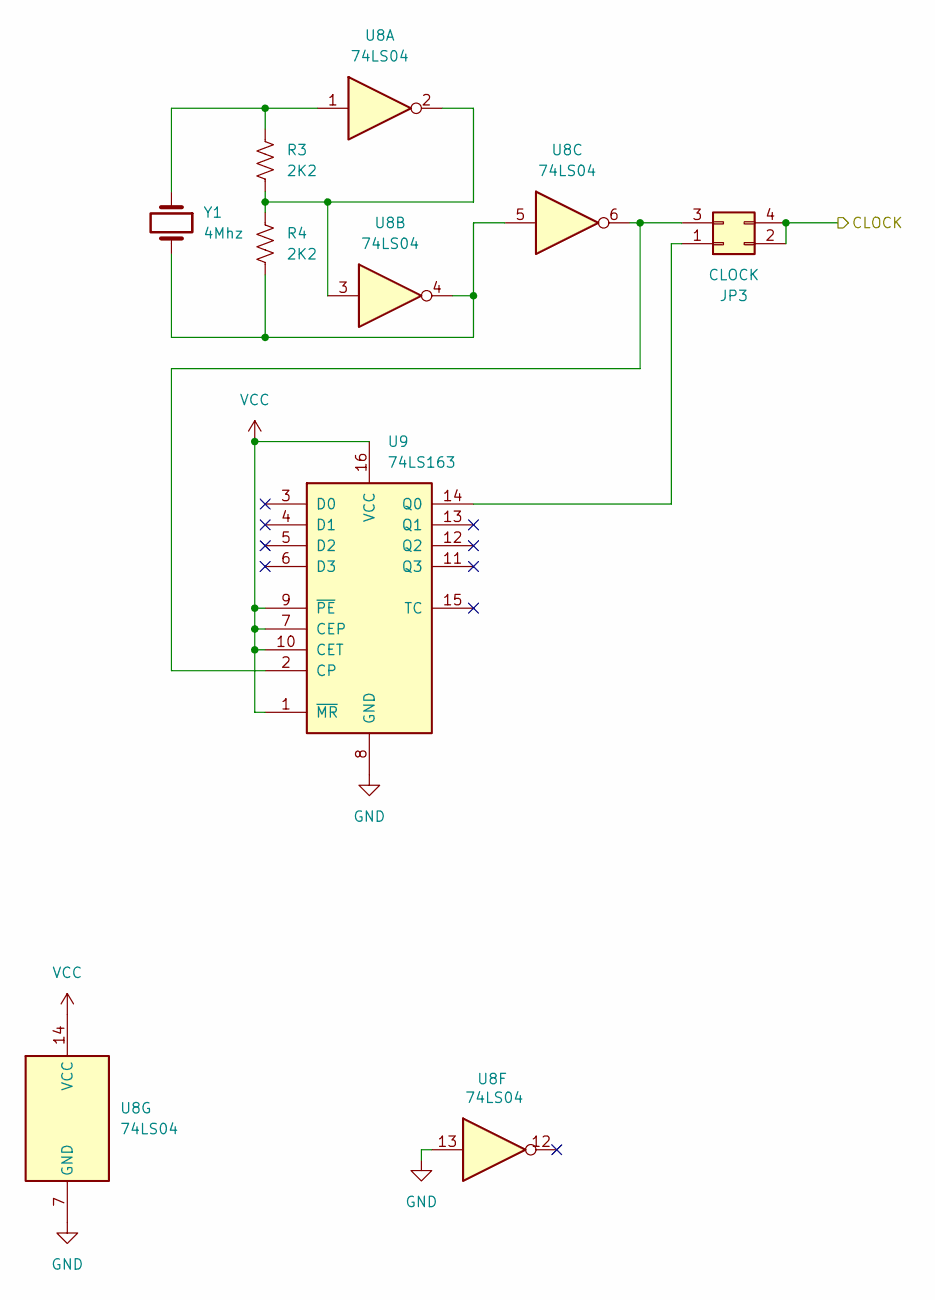
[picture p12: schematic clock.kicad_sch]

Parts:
JP3: CLOCK; PinHeader_2x02_P2.54mm_Vertical
R3, R4: 2K2; R_Axial_DIN0207_L6.3mm_D2.5mm_P7.62mm_Horizontal
U8: 74LS04
U9: 74LS163; DIP-16_W7.62mm_Socket
Y1: 4Mhz; Crystal_HC49-4H_Vertical

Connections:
/CLOCK: JP3.2, JP3.4; also elsewhere on the board
GND: U8.7 (GND), U8.13, U9.8 (GND); also elsewhere on the board
unnamed: JP3.1, U9.14 (Q0)
unnamed: JP3.3, U8.6, U9.2 (CP)
unnamed: R3.1, R4.2, U8.2, U8.3
unnamed: R3.2, U8.1, Y1.1
unnamed: R4.1, U8.4, U8.5, Y1.2
VCC: U8.14 (VCC), U9.1 (~MR), U9.7 (CEP), U9.9 (~PE), U9.10 (CET), U9.16 (VCC); also elsewhere on the board

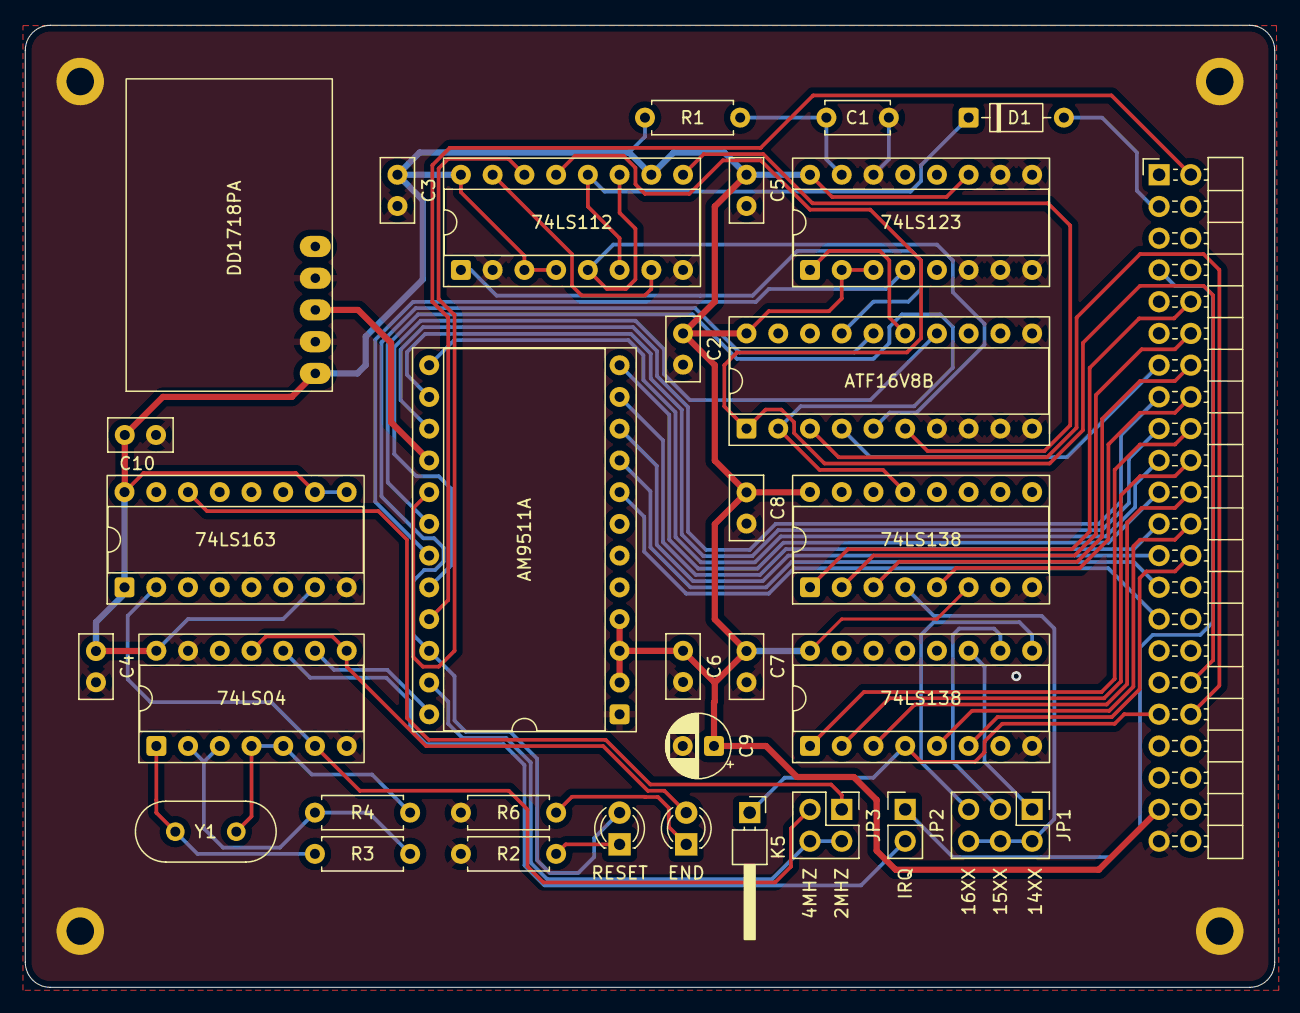
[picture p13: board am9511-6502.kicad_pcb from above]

Board: 2 copper layers, 100.0 x 77.0 mm, 37 parts (0 on the bottom side), 54 nets.

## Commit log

2025-07-10 additional PCB cleanup
    [am9511-6502.kicad_pcb, am9511-6502.kicad_sch, miscellany.kicad_sch]
2025-07-10 include gerbers in the repo
    [am9511-6502-B_Cu.gbr, am9511-6502-B_Mask.gbr, am9511-6502-B_Paste.gbr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]
2025-07-11 reset schematic annotations
    [am9511-6502-B_Cu.gbr, am9511-6502-B_Mask.gbr, am9511-6502-B_Paste.gbr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]
2025-07-24 add photo of board
2025-07-26 minor revisions to circuit description
2025-07-26 add PCBway review
2025-07-26 add PCBWay links on main page
2026-07-03 Add PAL-2 expansion connection and CS
    [am9511-6502.kicad_sch, miscellany.kicad_sch]
2026-07-07 Initial PAL-2 version
    [am9511-6502.kicad_pcb, am9511-6502.kicad_sch, clock.kicad_sch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]
2026-07-08 First manufacturing prototype
    [am9511-6502.kicad_pcb, am9511-6502.kicad_sch]
2026-08-16 Remove redundant files
    [am9511-6502-B_Cu.gbr, am9511-6502-B_Mask.gbr, am9511-6502-B_Paste.gbr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]
2026-08-16 Minor improvements to schematic
    [am9511-6502.kicad_sch]
2026-08-30 Remove debug 'print' statements
2026-09-09 Change base address
    [am9511-6502.kicad_pcb, miscellany.kicad_sch]
2026-10-07 Minor improvements
    [am9511-6502.kicad_pcb, am9511-6502.kicad_sch, miscellany.kicad_sch]

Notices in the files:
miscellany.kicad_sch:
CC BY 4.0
